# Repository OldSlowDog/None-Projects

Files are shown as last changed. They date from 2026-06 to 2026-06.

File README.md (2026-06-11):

# None-Projects

一个存放各种**小项目 / 实验 / 工具**的集合仓库。

---

## 项目索引

### 已收录项目

| 项目路径 | 名称 | 描述 |
|---|---|---|
| [`ESP32-S/Fan/`](./ESP32-S/Fan/) | ESP32-S 自制制冷风扇 | ESP32 驱动的 DIY 制冷风扇控制器（初设，安全性无法保障，仅供参考） |

### 目录结构

```
None-Projects/
├── ESP32-S/
│   └── Fan/                      # ESP32-S 风扇控制器项目
│       ├── smart_fan_controller/ # Arduino 固件
│       ├── 3D-Models/            # 结构件 3D 模型
│       ├── README.md
│       └── .gitignore
├── README.md                     # 本文件（项目总索引）
└── .gitignore                    # 全局忽略规则
```

---

## 仓库说明

本仓库用于收录各种**小型项目**，按**硬件平台 / 功能分类**组织目录。

每个独立项目拥有：
- 自己的 `README.md` — 说明项目详情、使用方法、依赖
- 自己的 `.gitignore` — 项目级忽略规则
- 独立的源代码 / 设计文件

---

## 新增项目指南

1. 选择合适的分类目录（如 `ESP32-S/`、`STM32/`、`Tools/` 等）
2. 在分类目录下创建项目文件夹
3. 编写项目级 `README.md` 和 `.gitignore`
4. 提交 Pull Request 或直接推送

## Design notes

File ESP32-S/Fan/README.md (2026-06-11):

# ESP32-S Smart Fan Controller (自制制冷风扇)

> **⚠️ 免责声明 / Disclaimer**
>
> 本项目的初始设计（V2.6）存在以下已知问题：
>
> | 问题 | 说明 |
> |------|------|
> | 💰 **成本高** | 材料与元器件选型成本远高于成品方案 |
> | 🔊 **噪音大** | 多风扇 + 风道设计不佳，运行噪音明显 |
> | ⚡ **不安全** | 自组电路缺乏专业保护，存在短路、过载等隐患 |
> | 🌬️ **风量小** | 风道/散热结构设计不合理，实际制冷效果有限 |
> | 🕸️ **布线乱** | 手工飞线，走线混乱，维护困难 |
> | 🔋 **耗电大** | TEC 半导体制冷片 + 多风扇同时运行功耗较高 |
> | 💧 **漏水风险** | 冷凝水处理未完善，有短路及损坏风险 |
>
> **本项目为个人 DIY 初设，安全性无法保障。** 强烈建议:
> - 自行重新设计结构模型和电路方案
> - 添加保险丝、温度保护、漏电保护等安全措施
> - 本项目内容**仅供参考，任何直接使用造成的损失由使用者自行承担**

基于 ESP32-S 的自制制冷风扇控制器，支持双风扇调速、TEC 半导体制冷片控制、温度监测、OLED 菜单及 WiFi 控制等功能。

---

## 功能特性

| 功能 | 描述 |
|---|---|
| **CPU 风扇控制** | GPIO15 输出 25kHz PWM，0-100% 无级调速，带物理电源开关 (GPIO12) |
| **主风扇控制** | GPIO13 输出 50Hz 舵机协议 PWM，支持电调（ESC）控制，带软启动斜坡 |
| **TEC 制冷片** | GPIO2 MOS 继电器开关控制，开启时自动强制 CPU 风扇 ≥ 50% |
| **双温度传感** | 两路 DS18B20（冷端 GPIO19 + 热端 GPIO16），12 位分辨率 |
| **转速反馈** | 两路 FG 信号输入（GPIO17/GPIO18），中断计数，理论转速映射 |
| **OLED 显示** | I2C SSD1306 128×64（SDA=21, SCL=22），单按键菜单系统 |
| **按键控制** | GPIO4 单按键，支持短按（换列）/ 双击（换行）/ 长按（确认） |
| **雾化器控制** | GPIO25 模拟微动按键序列（高→低→高） |
| **WiFi 控制** | AP 模式（ESP32_FAN_CTRL）+ HTTP 服务器（端口 80）Web 界面 |
| **串口控制** | 115200bps，JSON 响应格式（MF/C/T/H/F） |
| **硬件 MCPWM** | ESP32 原生 MCPWM 外设，无需手动模拟 |
| **安全保护** | 冷端/热端温度超限告警，LED 闪烁指示 |

---

## 硬件引脚定义

| 引脚 | 功能 | 备注 |
|---|---|---|
| GPIO2 | TEC 半导体制冷片 + LED 状态指示 | MOS 继电器，开关量 |
| GPIO4 | 物理按键输入 | INPUT_PULLUP，低电平有效 |
| GPIO12 | CPU 风扇电源开关 | 高电平=开 |
| GPIO13 | 主风扇 PWM（电调 50Hz） | MCPWM1B |
| GPIO15 | CPU 风扇 PWM（25kHz） | MCPWM0A |
| GPIO17 | CPU 风扇 FG 测速 | 上拉，下降沿中断 |
| GPIO18 | 主风扇 FG 测速 | 上拉，下降沿中断 |
| GPIO19 | DS18B20 冷端温度 | OneWire |
| GPIO16 | DS18B20 热端温度 | OneWire |
| GPIO21 | OLED SDA | I2C |
| GPIO22 | OLED SCL | I2C |
| GPIO25 | 雾化器控制 | 推挽输出，模拟按键 |
| GPIO14/23/26 | GND 替代引脚 | 输出低电平 |

---

## 目录结构

```
ESP32-S/Fan/
├── smart_fan_controller/
│   └── smart_fan_controller.ino    # Arduino 主程序 (V2.6)
├── 3D-Models/                      # 外壳/结构件 3D 打印文件
│   ├── 底座.stp                    # 底座
│   ├── 顶盖.stp                    # 顶盖
│   ├── 上风筒.stp                  # 上风筒
│   ├── 末风筒(上).stp              # 末风筒-上部
│   ├── 末风筒(下).stp              # 末风筒-下部
│   ├── 进风口.stp                  # 进风口
│   ├── 电机固定板.stp              # 电机固定板
│   ├── 半导体嵌装层.stp            # TEC 制冷片嵌装层
│   └── 隔离柱.stp                  # 隔离柱
├── README.md                       # 项目说明文档
└── .gitignore                      # Git 忽略规则
```

---

## 软件依赖

- **开发板**: ESP32 (Arduino Core for ESP32)
- **库依赖**:
  - `Wire` (内置) - I2C
  - `Adafruit GFX Library` - OLED 图形
  - `Adafruit SSD1306` - OLED 驱动
  - `OneWire` - DS18B20 总线
  - `DallasTemperature` - DS18B20 温度读取
  - `driver/mcpwm.h` (ESP32 SDK 内置) - 硬件 PWM
  - `WiFi` (内置) - WiFi
  - `WebServer` (内置) - HTTP 服务器

---

## 使用方法

### 1. 烧录固件

1. 安装 Arduino IDE + ESP32 开发板支持
2. 安装上述依赖库
3. 打开 `smart_fan_controller.ino`
4. 选择开发板：**ESP32 Dev Module**（或你的型号）
5. 选择正确的串口
6. 点击上传

### 2. OLED 菜单操作

```
C: 25.3°C  H: 32.1°C     ← 温度显示
^CPU[OFF][  ][Mid][Hi ]  ← CPU 风扇 (行0)
 FAN[OFF][Low][  ][Hi ]  ← 主风扇 (行1)
 TEC[OFF][ON ]            ← TEC 制冷 (行2)
 FOG[OFF][ON ]            ← 雾化器 (行3)
^=Row *=Col Long=OK       ← 操作提示
```

- **短按** → 切换当前行的选项（列）
- **双击** → 切换下一行
- **长按** → 确认选中的设置
- 当 TEC 为 ON 时，CPU 风扇 OFF/Low 被禁用（自动跳至 Mid 及以上）

### 3. WiFi Web 控制

1. 连接 WiFi **ESP32_FAN_CTRL**，密码 **12345678**
2. 浏览器打开 `http://192.168.4.1`
3. 点击 **Unlock** 解锁操作（3 秒无操作自动锁定）
4. 拖动滑块/点击按钮进行控制
5. 每 5 秒自动刷新状态

### 4. 串口命令

波特率 **115200**

| 命令 | 功能 |
|---|---|
| `OFF` | 全部关闭 |
| `C 50` | 设置 CPU 风扇占空比 (0-100) |
| `MF 50` | 设置主风扇占空比 (0-100) |
| `T 100` | 设置 TEC 开关 (0=OFF, 100=ON) |

响应示例：`{MF:"50",C:"60",T:"100",H:"35.2"}`

---

## 参数调整

在 `smart_fan_controller.ino` 顶部宏定义区域修改：

```cpp
#define WIFI_SSID   "ESP32_FAN_CTRL"   // WiFi 名称
#define WIFI_PASS   "12345678"          // WiFi 密码
#define TEMP_MAX_COLD  60.0             // 冷端安全温度
#define TEMP_MAX_HOT   70.0             // 热端安全温度
#define PULSE_MIN  1000                 // 电调最小脉宽（us）
#define PULSE_MAX  1500                 // 电调最大脉宽（us）
#define RAMP_RATE  200                  // 主风扇软启动速率（us/s）
```

---

## 版本历史

- **V2.6** - 简化安全逻辑，统一 JSON 响应，添加雾化器控制
- **V2.x** - 硬件 MCPWM，WiFi HTTP 界面，单按键菜单
- **V1.x** - 基础风扇+TEC 控制

---

## 注意事项

1. **TEC 开启后 CPU 风扇不会低于 50%** — 保护制冷片不致过热损坏
2. **电调信号** 使用标准 1000-1500μs 脉宽（可根据实际电调调整）
3. **DS18B20 未连接** 时显示 `--.-`，程序继续运行（每 60 秒警告一次）
4. **雾化器控制** 为模拟微动按键（50ms 低电平脉冲），需配合支持的雾化器模块
5. STP 文件为 STEP 格式，可直接在主流 CAD 软件（SolidWorks、Fusion 360、FreeCAD）中打开

## License

项目归属于 [OldSlowDog/None-Projects](https://github.com/OldSlowDog/None-Projects) 仓库

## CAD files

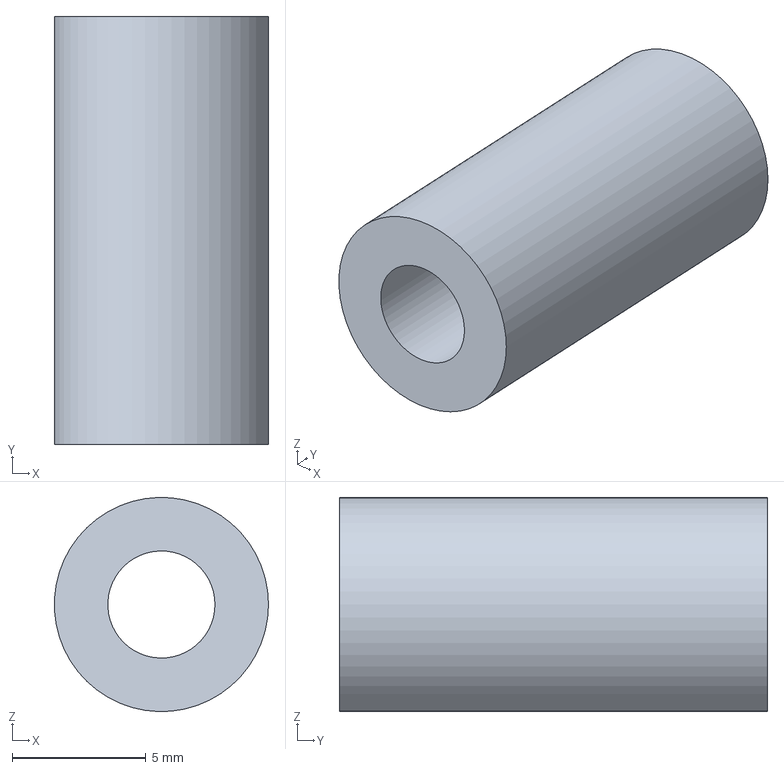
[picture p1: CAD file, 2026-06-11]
ESP32-S/Fan/3D-Models/隔离柱.stp
7.99 x 16.0 x 8.00 mm

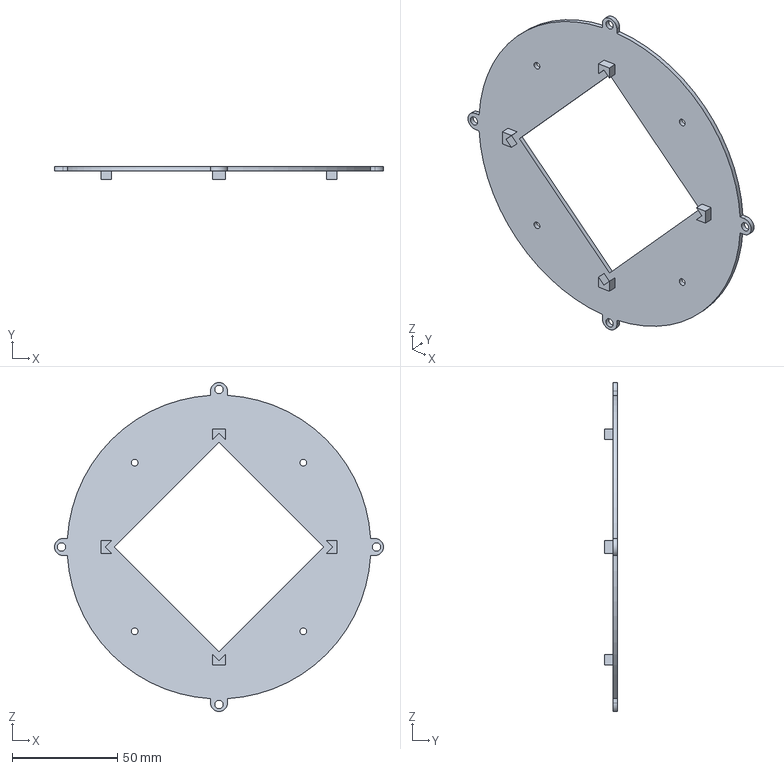
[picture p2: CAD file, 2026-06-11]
ESP32-S/Fan/3D-Models/上风筒.stp
156.0 x 6.00 x 156.0 mm

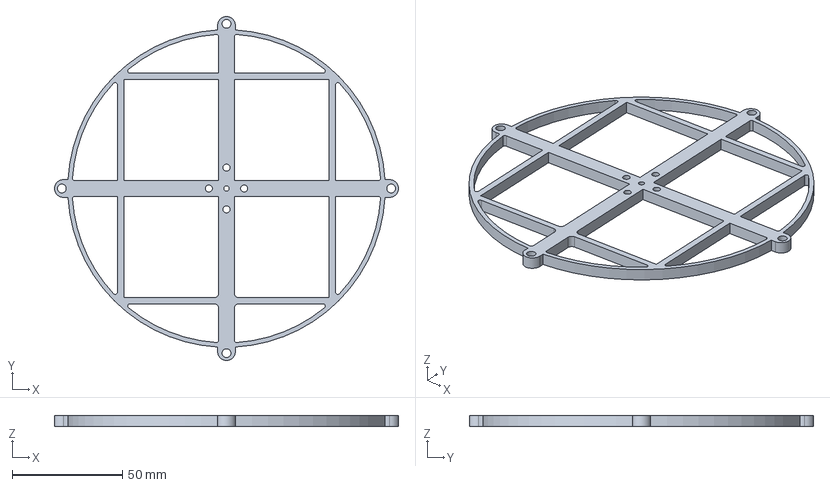
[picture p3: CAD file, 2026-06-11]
ESP32-S/Fan/3D-Models/电机固定板.stp
156.0 x 156.0 x 5.00 mm

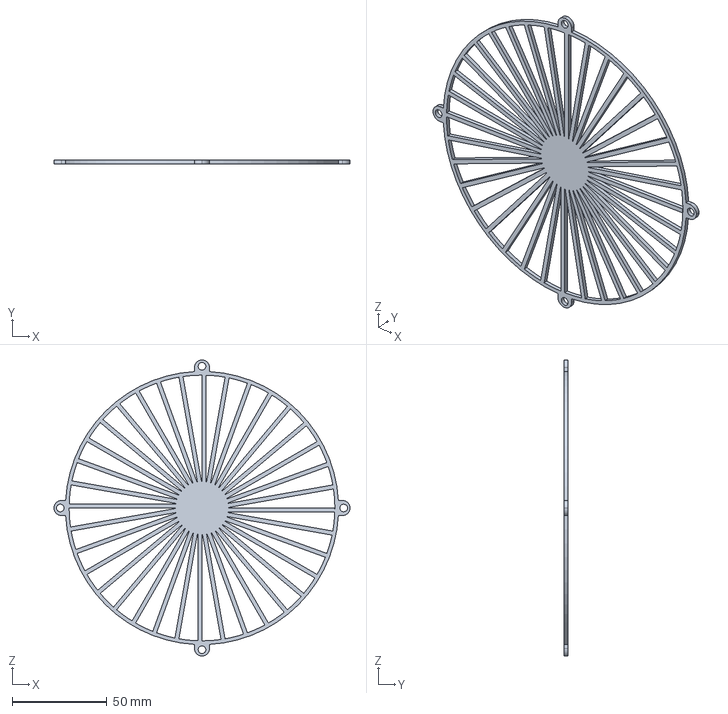
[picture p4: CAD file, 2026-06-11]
ESP32-S/Fan/3D-Models/顶盖.stp
156.0 x 2.00 x 156.0 mm

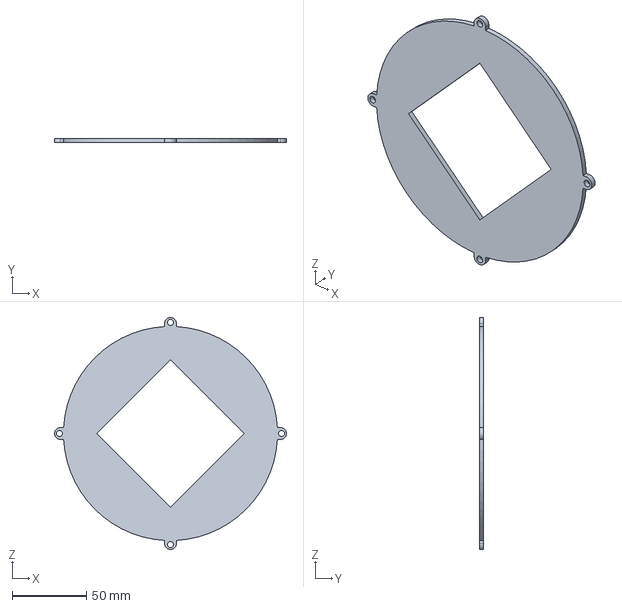
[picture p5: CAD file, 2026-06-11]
ESP32-S/Fan/3D-Models/进风口.stp
156.0 x 3.00 x 156.0 mm

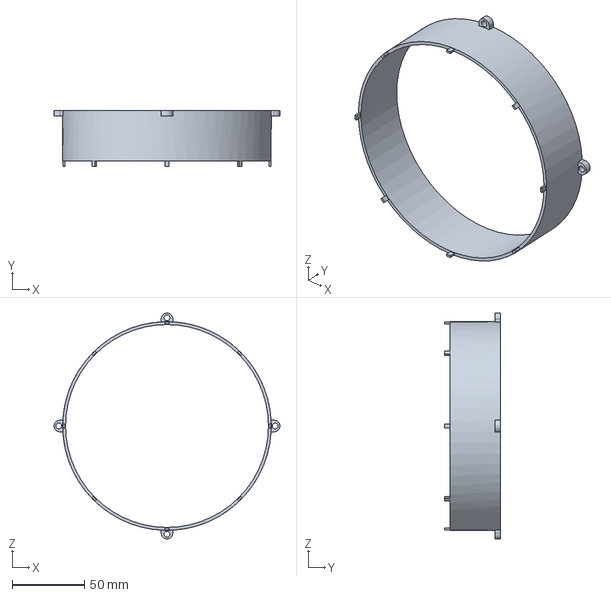
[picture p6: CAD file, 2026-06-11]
ESP32-S/Fan/3D-Models/末风筒(上).stp
156.0 x 39.0 x 156.0 mm

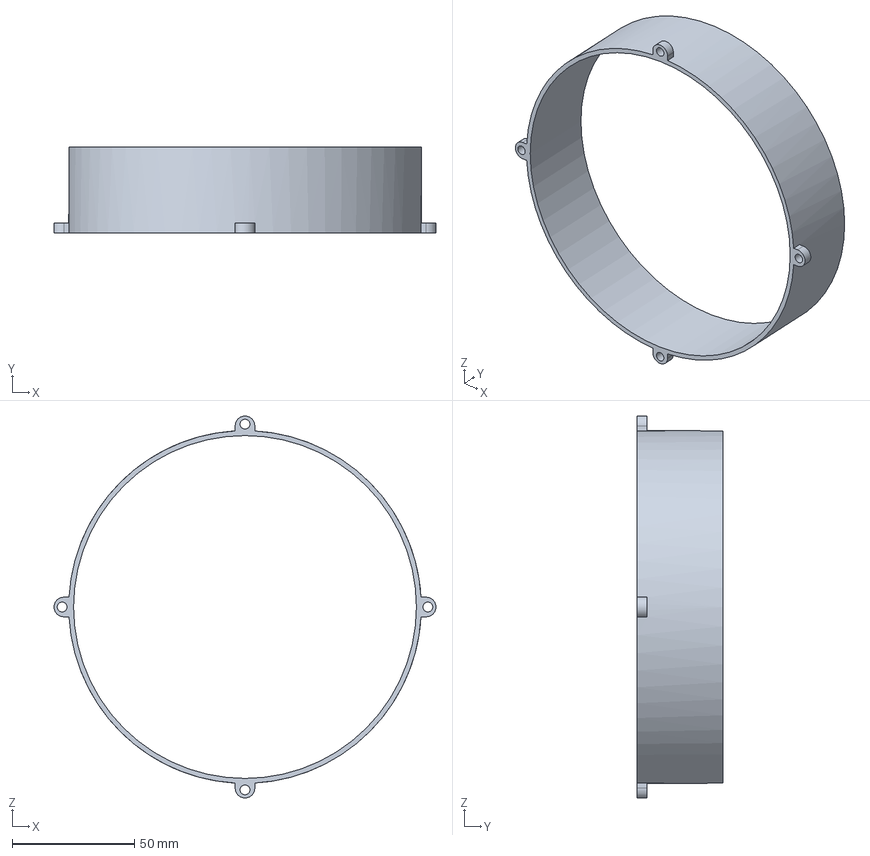
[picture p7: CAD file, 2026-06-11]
ESP32-S/Fan/3D-Models/末风筒(下).stp
156.0 x 35.0 x 156.0 mm

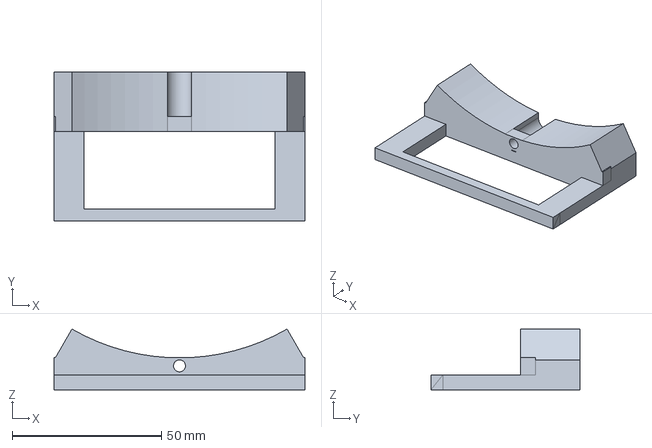
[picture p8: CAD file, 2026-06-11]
ESP32-S/Fan/3D-Models/底座.stp
84.0 x 50.0 x 20.4 mm

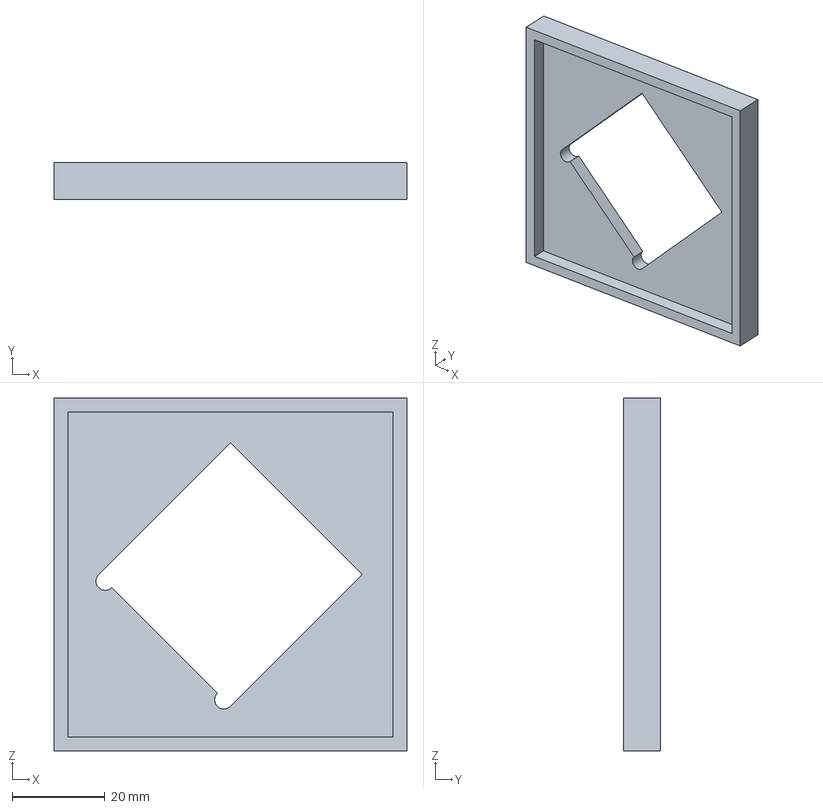
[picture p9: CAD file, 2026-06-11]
ESP32-S/Fan/3D-Models/半导体嵌装层.stp
76.3 x 8.00 x 76.3 mm

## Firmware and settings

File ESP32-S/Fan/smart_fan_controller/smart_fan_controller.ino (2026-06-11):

/*
 * ESP32-S Professional Refrigeration Controller V2.6
 * 
 * 功能:
 * 1. 无级调速0-100% (CPU风扇 + 主风扇) - 全硬件MCPWM
 * 2. CPU风扇物理开关 + 简化逻辑
 * 3. CPU风扇转速显示 (理论转速)
 * 4. 双DS18B20温度传感器 (冷端 + 热端)
 * 5. PWM MOS继电器控制半导体制冷片 (TEC)
 * 6. I2C OLED单按键菜单显示
 * 7. 3个GND替代引脚
 * 8. WIFI热点 + TCP服务器
 * 9. 串口+TCP统一JSON指令集
 * 
 * V2.6更新: 简化所有安全逻辑，简化指令集，JSON响应
 */

#include <Arduino.h>
#include <Wire.h>
#include <Adafruit_GFX.h>
#include <Adafruit_SSD1306.h>
#include <OneWire.h>
#include <DallasTemperature.h>
#include <driver/mcpwm.h>
#include <WiFi.h>
#include <WebServer.h>

/* ==================== 引脚定义 ==================== */
/* PWM输出 */
#define PIN_FAN_CPU      15       /* GPIO15 -> CPU散热风扇PWM (25kHz) */
#define PIN_FAN_MAIN     13       /* GPIO13 -> 主风扇电调信号 (50Hz) */
#define PIN_TEC          2        /* GPIO2 -> TEC半导体制冷片MOS继电器 (开关) */

/* CPU风扇物理开关 (MOS/继电器, 控制风扇电源或PWM使能) */
#define PIN_FAN_CPU_SW   12      /* GPIO12 -> CPU风扇电源开关 (高电平=开, 低电平=关) */

/* 测速输入 (FG信号, 上拉) */
#define PIN_FG_CPU       17      /* GPIO17 -> CPU风扇测速脉冲输入 */
#define PIN_FG_MAIN      18      /* GPIO18 -> 主风扇测速脉冲输入(可选) */

/* 温度传感器 DS18B20 */
#define PIN_TEMP_COLD    19      /* GPIO19 -> 冷端温度传感器 */
#define PIN_TEMP_HOT     16      /* GPIO16 -> 热端温度传感器 */

/* I2C OLED */
#define OLED_SDA         21      /* GPIO21 SDA */
#define OLED_SCL         22      /* GPIO22 SCL */
#define OLED_ADDR        0x3C    /* SSD1306地址 */
#define SCREEN_WIDTH     128
#define SCREEN_HEIGHT    64

/* LED状态指示 - 与TEC同步显示, 使用同一引脚 */
#define PIN_LED          PIN_TEC    /* GPIO17 板载LED - 与TEC同步 */

/* 物理按键 (单键菜单) */
#define PIN_BTN          4      /* GPIO4 -> 菜单按键 (上拉输入, 低电平有效) */

/* GND替代引脚 */
#define PIN_GND_REPLACEMENT1   23   /* GPIO23 -> GND替代引脚1 (OUTPUT LOW) */
#define PIN_GND_REPLACEMENT2   14   /* GPIO14 -> GND替代引脚2 (OUTPUT LOW) */
#define PIN_GND_REPLACEMENT3   26   /* GPIO26 -> GND替代引脚3 (OUTPUT LOW) */

/* 雾化器控制引脚 */
#define PIN_FOGGER 25 /* GPIO25 -> 雾化器模拟按键输出 (推挽) */

/* ==================== 按键参数 ==================== */
#define BTN_DEBOUNCE_MS  20      /* 按键去抖动 ms */
#define BTN_SHORT_MIN    50      /* 短按最小时间 ms */
#define BTN_SHORT_MAX    300     /* 短按最大时间 ms */
#define BTN_LONG_MIN     500     /* 长按最小时间 ms */

/* ==================== WIFI和HTTP参数 ==================== */
#define WIFI_SSID        "ESP32_FAN_CTRL"  /* WIFI热点名称 */
#define WIFI_PASS        "12345678"        /* WIFI热点密码 */
#define HTTP_PORT        80                /* HTTP服务器端口 */

/* ==================== PWM参数 ==================== */
#define CPU_FAN_FREQ     25000   /* CPU风扇 25kHz标准频率 */
#define MAIN_FAN_FREQ    50      /* 主风扇电调 50Hz舵机协议 */
#define TEC_FREQ         1000    /* TEC控制 1kHz PWM */
#define PULSE_PERIOD     20000   /* 电调周期 20ms */
#define PULSE_MIN        1000    /* 电调最小脉宽 us */
#define PULSE_MAX        1500    /* 电调最大脉宽 us */

/* 占空比0-100% */

/* ==================== 测速参数 ==================== */
#define FG_SAMPLE_MS     1000    /* 测速采样周期 ms */
#define PULSES_PER_REV   2       /* 每转FG脉冲数 (标准4线风扇=2) */
#define FG_DEBOUNCE_US   2000    /* 最小脉冲间隔 us (2ms) */
#define MAX_VALID_RPM    8000    /* 最大有效转速 */

/* 开环控制参数 - 理论转速映射 */
#define CPU_FAN_MAX_RPM  2000    /* CPU风扇最大额定转速 RPM */
#define MAIN_FAN_MAX_RPM 3000    /* 主风扇最大额定转速 RPM */

/* ==================== 菜单档位定义 ==================== */
enum FanSpeed {
    FAN_OFF = 0,                  /* 关闭 */
    FAN_LOW,                      /* 低速 (~30%) */
    FAN_MID,                      /* 中速 (~60%) */
    FAN_HIGH,                     /* 高速 (100%) */
    FAN_SPEED_COUNT               /* 档位总数 */
};

/* 档位对应的占空比 (%) */
const uint8_t CPU_DUTY_TABLE[FAN_SPEED_COUNT] = {0, 30, 60, 100};
const uint8_t MAIN_DUTY_TABLE[FAN_SPEED_COUNT] = {0, 30, 60, 100};
const char* const SPEED_NAMES[FAN_SPEED_COUNT] = {"OFF", "Low", "Mid", "Hi "};

/* TEC开关状态 */
enum TecState : uint8_t {
    TEC_OFF = 0,
    TEC_ON,
    TEC_STATE_COUNT
};
const char* const TEC_NAMES[TEC_STATE_COUNT] = {"OFF", "ON "};
enum FoggerState : uint8_t {
    FOGGER_OFF = 0,
    FOGGER_ON,
    FOGGER_STATE_COUNT
};
const char* const FOGGER_NAMES[FOGGER_STATE_COUNT] = {"OFF", "ON "};

/* ==================== 温度参数 ==================== */
#define TEMP_TARGET      25.0    /* 目标温度 °C */
#define TEMP_MAX_COLD    60.0    /* 冷端最大安全温度 */
#define TEMP_MAX_HOT     70.0    /* 热端最大安全温度 */

/* ==================== 全局变量 ==================== */
/* 风扇控制 */
uint8_t cpuFanDuty = 0;            /* 0-100% */
uint8_t mainFanDuty = 0;           /* 0-100% (映射到1000-1500us) */
uint8_t tecDuty = 0;               /* 0-100% TEC制冷功率 */

/* 测速反馈 */
volatile unsigned long cpuFgCount = 0;
volatile unsigned long mainFgCount = 0;
volatile unsigned long lastCpuFgTime = 0;
volatile unsigned long lastMainFgTime = 0;
unsigned int cpuRpm = 0;
unsigned int mainRpm = 0;
unsigned int cpuTheoreticalRpm = 0;
unsigned int mainTheoreticalRpm = 0;
unsigned long lastFgTime = 0;

/* 温度 */
float tempCold = 0.0;
float tempHot = 0.0;
float tempDelta = 0.0;

/* 控制模式 */
enum ControlMode {
    MODE_MANUAL = 0,
    MODE_AUTO
};
ControlMode ctrlMode = MODE_MANUAL;

/* 菜单状态 */
uint8_t cpuFanSpeedIdx = FAN_OFF;
uint8_t mainFanSpeedIdx = FAN_OFF;
uint8_t tecState = TEC_OFF;

/* CPU风扇物理开关状态 */
bool cpuFanSwState = false;

/* 主风扇PWM Ramp参数 */
#define RAMP_RATE 200    /* 每秒最大脉宽变化 (us/s) */
#define RAMP_UPDATE_INTERVAL 50 /* ramp更新间隔 (ms) */
uint16_t mainFanTargetPulse = 1000;
uint16_t mainFanDesiredPulse = 1000;

/* 按键状态 */
volatile unsigned long btnPressTime = 0;
volatile bool btnPressed = false;
volatile bool btnDebouncing = false;

unsigned long lastClickTime = 0;
const unsigned long DOUBLE_CLICK_WINDOW = 500;

enum BtnEvent {
    BTN_NONE = 0,
    BTN_SHORT_PRESS,
    BTN_LONG_PRESS,
    BTN_DOUBLE_CLICK,
};
BtnEvent lastBtnEvent = BTN_NONE;

/* 菜单行列选择状态 */
uint8_t menuCurrentRow = 0;
uint8_t menuCurrentCol = 0;

const uint8_t MAX_ROWS = 4;
const uint8_t COLS_PER_ROW[] = {4,4,2,2};

/* 显示刷新 */
unsigned long lastOledUpdate = 0;

/* 串口 */
String cmdBuffer = "";
const uint8_t CMD_TIMEOUT = 50;

/* DS18B20对象 */
OneWire oneWireCold(PIN_TEMP_COLD);
OneWire oneWireHot(PIN_TEMP_HOT);
DallasTemperature sensorCold(&oneWireCold);
DallasTemperature sensorHot(&oneWireHot);

/* OLED */
Adafruit_SSD1306 display(SCREEN_WIDTH, SCREEN_HEIGHT, &Wire, -1);

/* 雾化器状态 */
bool foggerOn = false; /* 初始关 */

/* WIFI和HTTP */
WebServer server(HTTP_PORT);

/* ==================== 函数声明 ==================== */
void toggleFogger();
void initWiFi();
void handleRoot();
void handleApiStatus();
void handleApiSet();
void initHardware();
void initPwm();
void initFgInterrupts();
void initSensors();
void initOled();
void initButton();
void initCpuFanSw();

void setCpuFan(uint8_t duty);
void setMainFan(uint8_t duty);
void setTec(uint8_t duty);
void setCpuFanSw(bool state);

void IRAM_ATTR cpuFgIsr();
void IRAM_ATTR mainFgIsr();
void calculateRpm();
uint16_t getTheoreticalRpm(uint8_t duty, uint16_t maxRpm);

void updateTemperatures();
void autoControlLoop();
void safetyCheck();
void updateMainFanRamp();

void updateOled();
void drawMenuScreen();

BtnEvent readButton();
void handleMenuEvent(BtnEvent event);
void applyMenuRowColSetting(uint8_t row, uint8_t col);
void applyMenuSettings();

void processCommand(String cmd);

/* ==================== 初始化 ==================== */
void setup() {
    Serial.begin(115200);
    Serial.println();
    Serial.println(F("========================================"));
    Serial.println(F("  ESP32 Pro Refrigeration Controller V2.6"));
    Serial.println(F("  Mode: OPEN-LOOP | Dual MCPWM | Single Button | WIFI TCP"));
    Serial.println(F("========================================"));
    
    // 首先立即设置雾化器引脚为高电平，防止上电初期误触发
    pinMode(PIN_FOGGER, OUTPUT);
    digitalWrite(PIN_FOGGER, HIGH);
    foggerOn = false;
    Serial.print(F("[FOGGER] Pin "));
    Serial.print(PIN_FOGGER);
    Serial.println(F(" initialized HIGH (prevent power-on glitch)"));
    
    // 给足够时间让系统稳定
    delay(1000);
    
    initHardware();
    initButton();
    initCpuFanSw();
    initPwm();
    initFgInterrupts();
    initSensors();
    initOled();
    initWiFi();
    
    cpuFanSpeedIdx = FAN_OFF;
    mainFanSpeedIdx = FAN_OFF;
    tecState = TEC_OFF;
    applyMenuSettings();
    
    display.clearDisplay();
    display.setTextSize(1);
    display.setTextColor(SSD1306_WHITE);
    display.setCursor(6, 24);
    display.print(F("Pro Cooler V2.6"));
    display.setCursor(4, 36);
    display.print(F("WIFI TCP"));
    display.setCursor(0, 48);
    display.print(F("^=Row *=Col Long=OK"));
    display.display();
    
    delay(800);
    
    Serial.println(F("[OK] System Ready!"));
    Serial.println();
}

void loop() {
    unsigned long now = millis();
    
    while (Serial.available()) {
        char c = Serial.read();
        
        if (c == '\n' || c == '\r') {
            if (cmdBuffer.length() > 0) {
                processCommand(cmdBuffer);
                cmdBuffer = "";
            }
        } else if (cmdBuffer.length() < 48) {
            cmdBuffer += c;
            
            char cc = c;
            if (cc >= 'a' && cc <= 'z') cc -= 32;
            
            if (cmdBuffer.length() == 1 && 
                (cc == 'O' || cc == 'F' || cc == 'A' || cc == 'M' ||
                 cc == 'T' || cc == 'S' || cc == '?' || cc == 'H' || cc == 'P')) {
                processCommand(cmdBuffer);
                cmdBuffer = "";
            }
        }
    }
    
    if (now - lastFgTime >= FG_SAMPLE_MS) {
        lastFgTime = now;
        calculateRpm();
    }
    
    static unsigned long lastTemp = 0;
    if (now - lastTemp >= 2000) {
        lastTemp = now;
        updateTemperatures();
        
        if (ctrlMode == MODE_AUTO) {
            autoControlLoop();
        }
        safetyCheck();
    }
    
    BtnEvent btnEvent = readButton();
    if (btnEvent != BTN_NONE) {
        handleMenuEvent(btnEvent);
    }
    
    updateMainFanRamp();
    
    if (now - lastOledUpdate >= 500) {
        lastOledUpdate = now;
        updateOled();
    }
    
    server.handleClient();
    
    delay(5);
}

/* ==================== 硬件初始化 ==================== */
void initHardware() {
    pinMode(PIN_LED, OUTPUT);
    digitalWrite(PIN_LED, LOW);
    
    Serial.println(F("[HW] GPIO Init OK"));
}

void initButton() {
    pinMode(PIN_BTN, INPUT_PULLUP);
    
    pinMode(PIN_GND_REPLACEMENT1, OUTPUT);
    digitalWrite(PIN_GND_REPLACEMENT1, LOW);
    
    pinMode(PIN_GND_REPLACEMENT2, OUTPUT);
    digitalWrite(PIN_GND_REPLACEMENT2, LOW);
    
    pinMode(PIN_GND_REPLACEMENT3, OUTPUT);
    digitalWrite(PIN_GND_REPLACEMENT3, LOW);
    
    // 雾化器引脚已在 setup() 最开始初始化，这里不再重复操作，防止误触发
    // 只确保当前状态是高电平
    digitalWrite(PIN_FOGGER, HIGH);
    
    btnPressed = false;
    btnDebouncing = false;
    btnPressTime = 0;
    lastBtnEvent = BTN_NONE;
    
    Serial.print(F("[BTN] BTN(GPIO"));
    Serial.print(PIN_BTN);
    Serial.print(F(")=PU_LOW, GND_EXT(GPIO"));
    Serial.print(PIN_GND_REPLACEMENT1);
    Serial.print(F("/"));
    Serial.print(PIN_GND_REPLACEMENT2);
    Serial.print(F("/"));
    Serial.print(PIN_GND_REPLACEMENT3);
    Serial.println(F(")=LOW"));
}

void initCpuFanSw() {
    pinMode(PIN_FAN_CPU_SW, OUTPUT);
    digitalWrite(PIN_FAN_CPU_SW, LOW);
    cpuFanSwState = false;
    
    Serial.print(F("[CPU_SW] Fan power switch on GPIO"));
    Serial.println(PIN_FAN_CPU_SW);
}

void setCpuFanSw(bool state) {
    cpuFanSwState = state;
    digitalWrite(PIN_FAN_CPU_SW, state ? HIGH : LOW);
}

BtnEvent readButton() {
    bool currentState = (digitalRead(PIN_BTN) == LOW);
    
    unsigned long now = millis();
    static unsigned long lastStateChange = 0;
    static bool lastState = false;
    static bool longPressFired = false;
    
    if (currentState != lastState) {
        if (!btnDebouncing) {
            btnDebouncing = true;
            lastStateChange = now;
        } else if (now - lastStateChange >= BTN_DEBOUNCE_MS) {
            btnDebouncing = false;
            lastState = currentState;
            
            if (currentState) {
                btnPressTime = now;
                btnPressed = true;
                longPressFired = false;
            } else {
                if (btnPressed) {
                    unsigned int pressDuration = now - btnPressTime;
                    btnPressed = false;
                    
                    if (pressDuration >= BTN_SHORT_MIN && pressDuration <= BTN_SHORT_MAX && !longPressFired) {
                        if ((now - lastClickTime) <= DOUBLE_CLICK_WINDOW) {
                            lastClickTime = 0;
                            return BTN_DOUBLE_CLICK;
                        } else {
                            lastClickTime = now;
                            return BTN_SHORT_PRESS;
                        }
                    }
                }
            }
        }
    }
    
    if (btnPressed && currentState) {
        unsigned int pressDuration = now - btnPressTime;
        if (pressDuration >= BTN_LONG_MIN && !longPressFired) {
            longPressFired = true;
            lastClickTime = 0;
            return BTN_LONG_PRESS;
        }
    }
    
    return BTN_NONE;
}

void initPwm() {
    mcpwm_gpio_init(MCPWM_UNIT_0, MCPWM0A, PIN_FAN_CPU);
    
    mcpwm_config_t cpu_pwm_config;
    cpu_pwm_config.frequency = CPU_FAN_FREQ;
    cpu_pwm_config.cmpr_a = 0.0;
    cpu_pwm_config.cmpr_b = 0.0;
    cpu_pwm_config.duty_mode = MCPWM_DUTY_MODE_0;
    cpu_pwm_config.counter_mode = MCPWM_UP_COUNTER;
    
    mcpwm_init(MCPWM_UNIT_0, MCPWM_TIMER_0, &cpu_pwm_config);
    
    mcpwm_gpio_init(MCPWM_UNIT_0, MCPWM1B, PIN_FAN_MAIN);
    
    mcpwm_config_t esc_pwm_config;
    esc_pwm_config.frequency = MAIN_FAN_FREQ;
    esc_pwm_config.cmpr_a = 0.0;
    esc_pwm_config.cmpr_b = 0.0;
    esc_pwm_config.duty_mode = MCPWM_DUTY_MODE_0;
    esc_pwm_config.counter_mode = MCPWM_UP_COUNTER;
    
    mcpwm_init(MCPWM_UNIT_0, MCPWM_TIMER_1, &esc_pwm_config);
    
    ledcDetachPin(PIN_TEC);
    pinMode(PIN_TEC, OUTPUT);
    digitalWrite(PIN_TEC, LOW);
    
    mcpwm_set_duty(MCPWM_UNIT_0, MCPWM_TIMER_0, MCPWM_OPR_A, 0.0);
    
    float initial_pulse_pct = (float)PULSE_MIN * 100.0 / PULSE_PERIOD;
    mcpwm_set_duty(MCPWM_UNIT_0, MCPWM_TIMER_1, MCPWM_OPR_B, initial_pulse_pct);
    mainFanTargetPulse = PULSE_MIN;
    mainFanDesiredPulse = PULSE_MIN;
    
    Serial.print(F("[PWM] CPU=25kHz(MCPWM0_T0_GPIO"));
    Serial.print(PIN_FAN_CPU);
    Serial.print(F("), Main=50Hz(MCPWM0_T1_GPIO"));
    Serial.print(PIN_FAN_MAIN);
    Serial.print(F("), TEC=GPIO"));
    Serial.print(PIN_TEC);
    Serial.println(F("(开关)"));
}

void initFgInterrupts() {
    pinMode(PIN_FG_CPU, INPUT_PULLUP);
    attachInterrupt(digitalPinToInterrupt(PIN_FG_CPU), cpuFgIsr, FALLING);
    
    pinMode(PIN_FG_MAIN, INPUT_PULLUP);
    attachInterrupt(digitalPinToInterrupt(PIN_FG_MAIN), mainFgIsr, FALLING);
    
    Serial.print(F("[FG] CPU=GPIO"));
    Serial.print(PIN_FG_CPU);
    Serial.print(F(", Main=GPIO"));
    Serial.println(PIN_FG_MAIN);
}

void initSensors() {
    pinMode(PIN_TEMP_COLD, INPUT_PULLUP);
    pinMode(PIN_TEMP_HOT, INPUT_PULLUP);
    
    sensorCold.begin();
    sensorHot.begin();
    
    sensorCold.setResolution(12);
    sensorHot.setResolution(12);
    
    int nCold = sensorCold.getDeviceCount();
    int nHot = sensorHot.getDeviceCount();
    
    Serial.print(F("[TEMP] Cold DS18B20(GPIO"));
    Serial.print(PIN_TEMP_COLD);
    Serial.print(F("): "));
    Serial.print(nCold);
    Serial.print(F(" device(s), Hot DS18B20(GPIO"));
    Serial.print(PIN_TEMP_HOT);
    Serial.print(F("): "));
    Serial.println(nHot);
    
    if (nCold == 0 && nHot == 0) {
        Serial.println(F("[WARN] No DS18B20 detected!"));
    }
}

void initOled() {
    Wire.begin(OLED_SDA, OLED_SCL);
    
    if (!display.begin(SSD1306_SWITCHCAPVCC, OLED_ADDR)) {
        Serial.println(F("[ERR] SSD1306 failed!"));
    } else {
        display.clearDisplay();
        display.display();
        Serial.print(F("[OLED] SSD1306@0x"));
        Serial.print(OLED_ADDR, HEX);
        Serial.println(F(" OK"));
    }
}
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

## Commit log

2026-06-11 feat: add ESP32-S Smart Fan Controller project
    - Add ESP32-S/Fan/ smart fan controller project
    - Include Arduino firmware (smart_fan_controller.ino V2.6)
    - Include 9x STP 3D model files for enclosure/structure
    - Add project README with pinout, features, usage guide
    - Add root README for project index
    - Add appropriate .gitignore files
    [上风筒.stp, 半导体嵌装层.stp, 底座.stp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]
2026-06-11 docs: add prominent disclaimer about DIY safety and known issues
    - Add warning block at top of README listing all known shortcomings
    (high cost, loud noise, unsafe, low airflow, messy wiring,
    high power consumption, water leakage)
    - State it's a preliminary design with no safety guarantee
    - Recommend users design their own models, for reference only
2026-06-11 docs: add demonstration video of the smart fan controller in action
